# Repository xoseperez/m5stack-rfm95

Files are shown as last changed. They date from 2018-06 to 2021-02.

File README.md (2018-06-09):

# M5Stack TTN Node

This is a LoRaWAN node based on the great M5Stack development platform.
It uses a RFM95 by HopeRF and the standard LMIC stack.
The sample code is configured to connect to The Things Network using EU frequency, but you can easily change that.






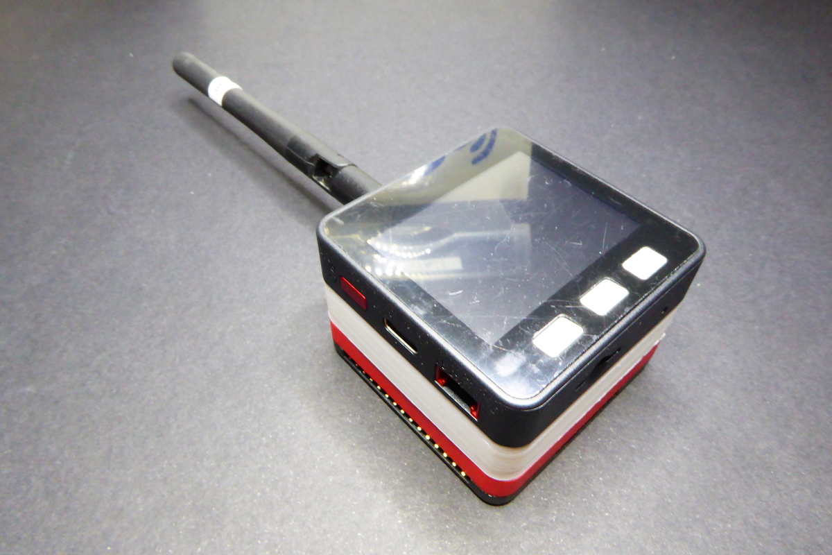
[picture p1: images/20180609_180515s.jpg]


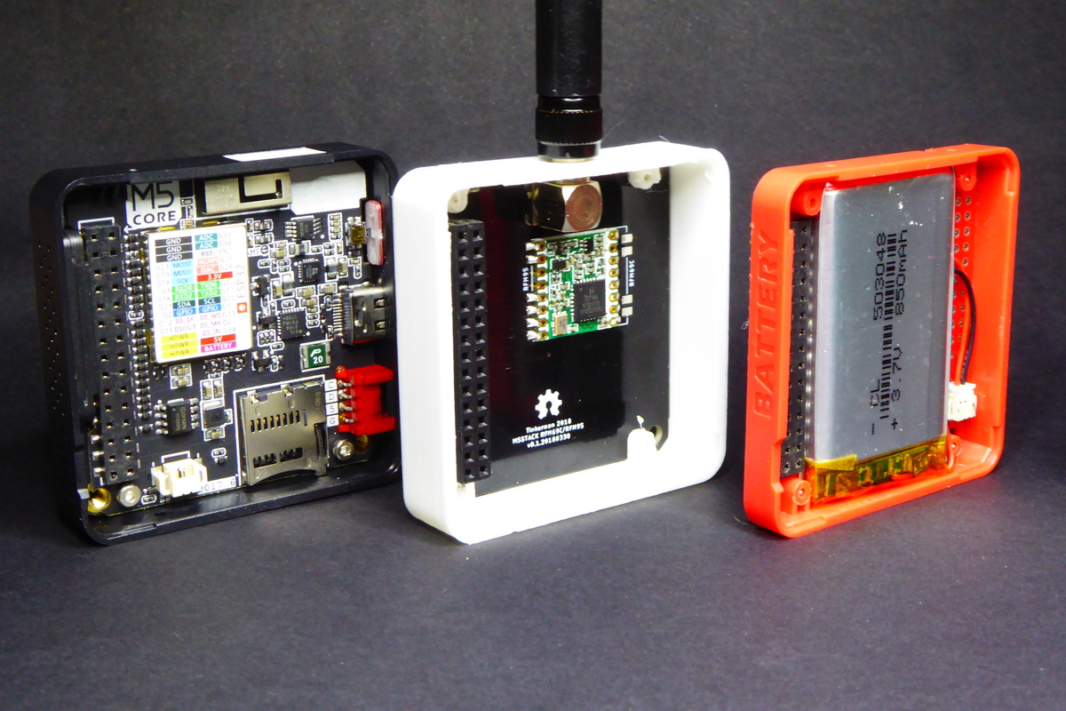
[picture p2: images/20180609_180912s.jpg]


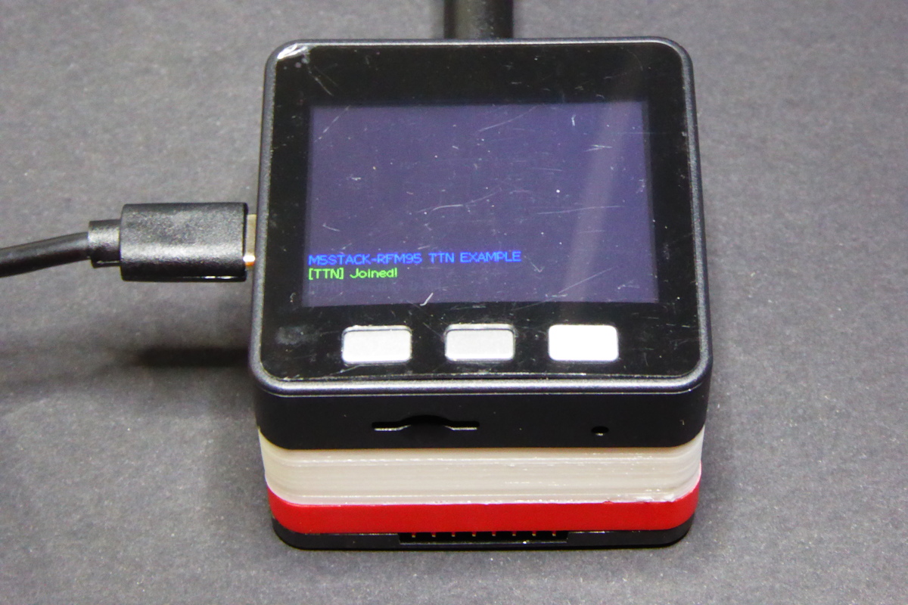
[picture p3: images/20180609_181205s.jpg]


This repository contains:

* PCB schematics, layout (for Eagle) and gerbers.
* 3D model of different enclosure options (bottom layer, middle layer), both OpenSCAD and STL files.
* Sample code that sends an auto-increment number and sleeps the board.

## License

Copyright (C) 2018 by Xose Pérez (@xoseperez)

This program is free software: you can redistribute it and/or modify
it under the terms of the GNU General Public License as published by
the Free Software Foundation, either version 3 of the License, or
(at your option) any later version.

This program is distributed in the hope that it will be useful,
but WITHOUT ANY WARRANTY; without even the implied warranty of
MERCHANTABILITY or FITNESS FOR A PARTICULAR PURPOSE.  See the
GNU General Public License for more details.

You should have received a copy of the GNU General Public License
along with this program.  If not, see <http://www.gnu.org/licenses/>.

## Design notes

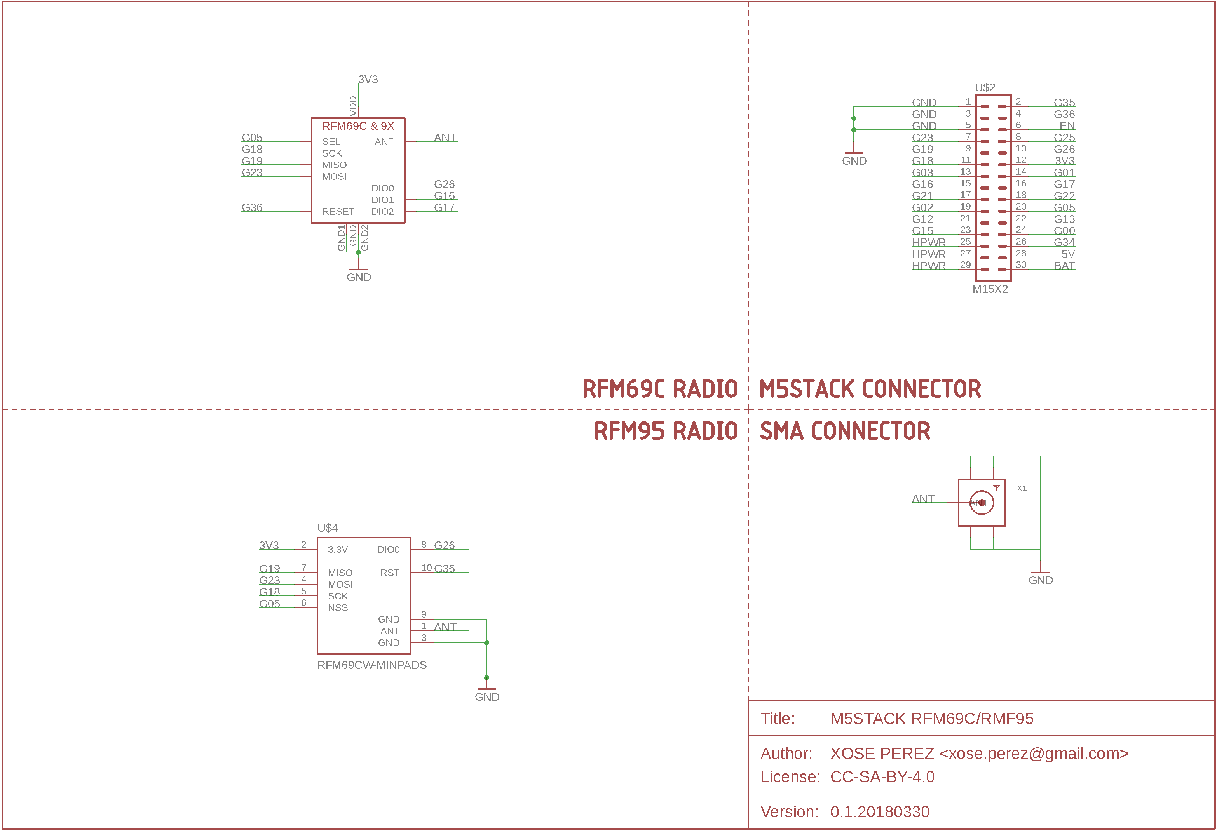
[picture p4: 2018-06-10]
pcb/m5stack-rfm95.v1.0.20180330.schematic.png

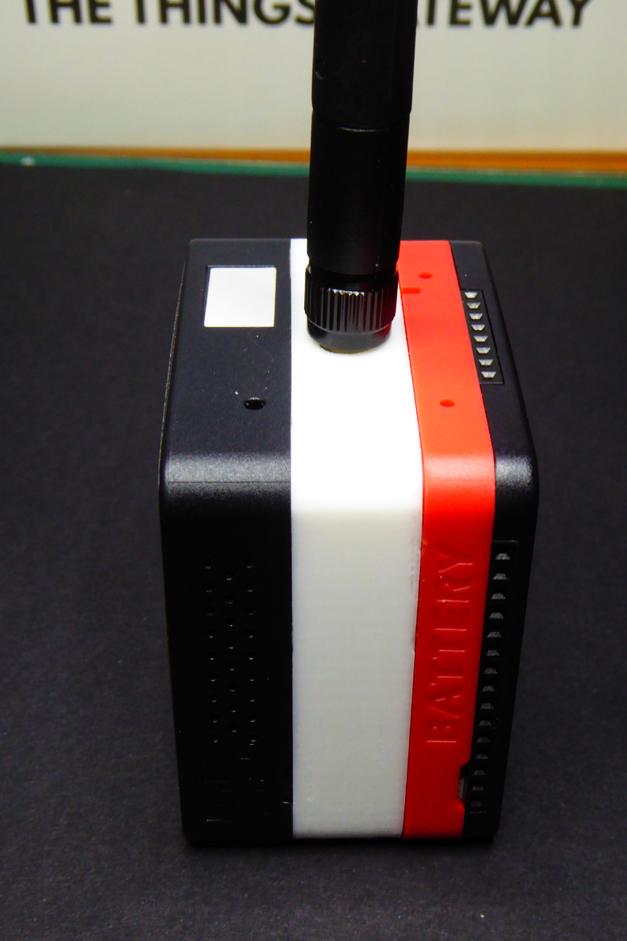
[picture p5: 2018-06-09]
images/20180609_180540s.jpg

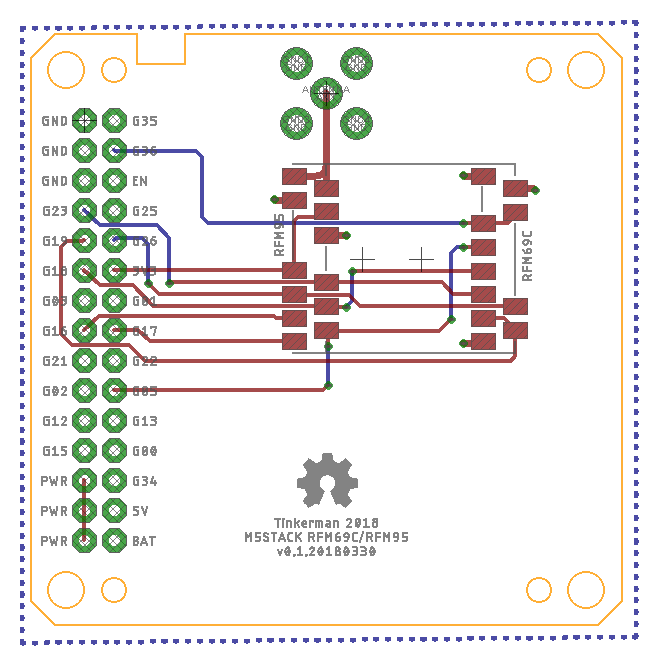
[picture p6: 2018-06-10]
pcb/m5stack-rfm95.v1.0.20180330.layout.png

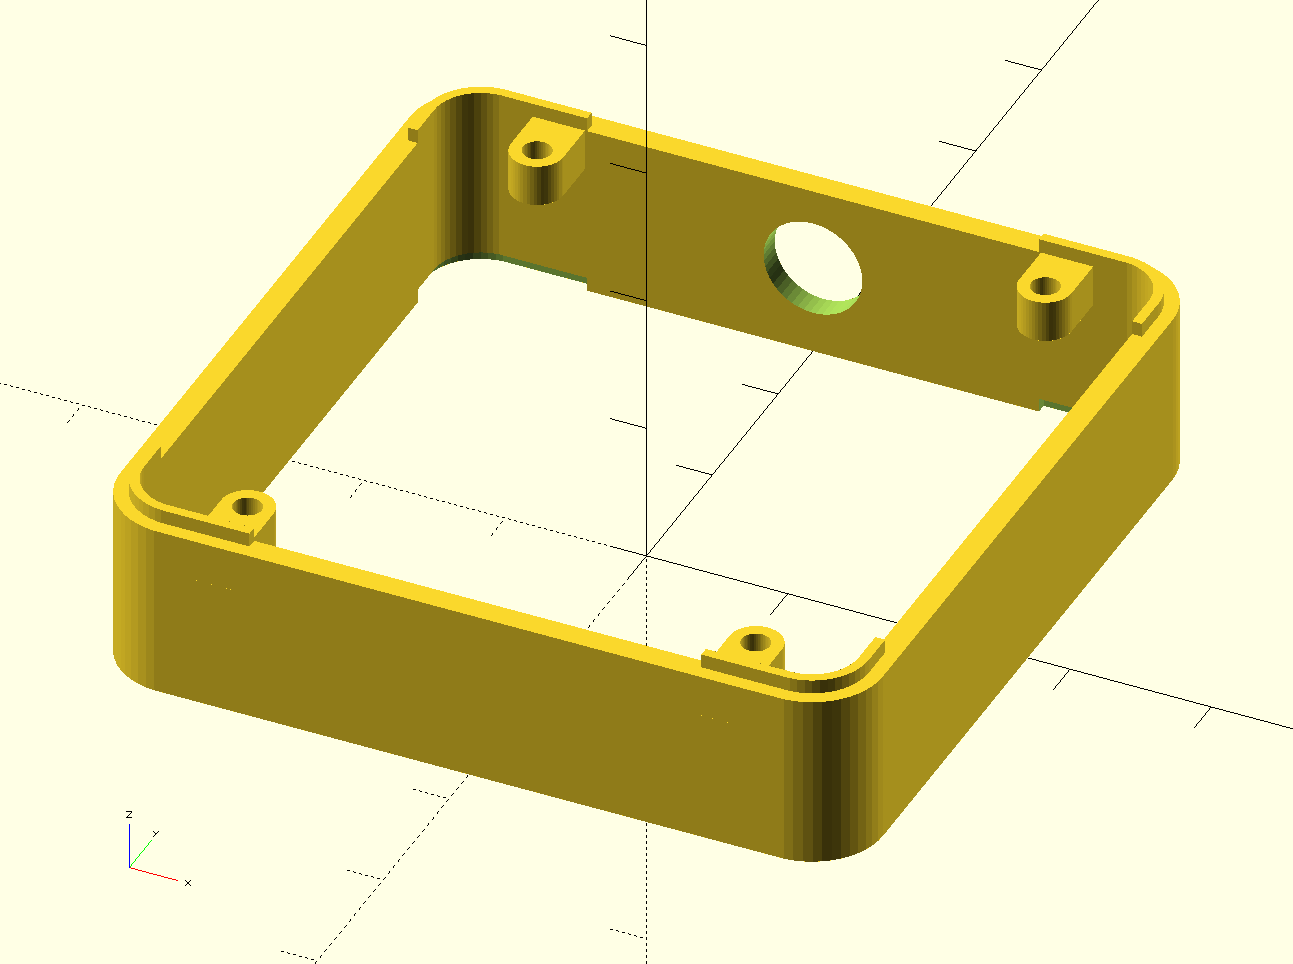
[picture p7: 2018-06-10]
enclosure/m5stack-rfm95.middle.png

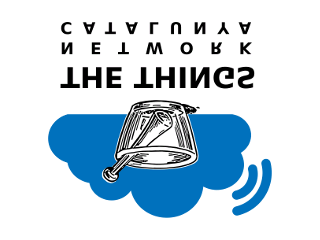
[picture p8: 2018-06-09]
tools/ttncat.bmp

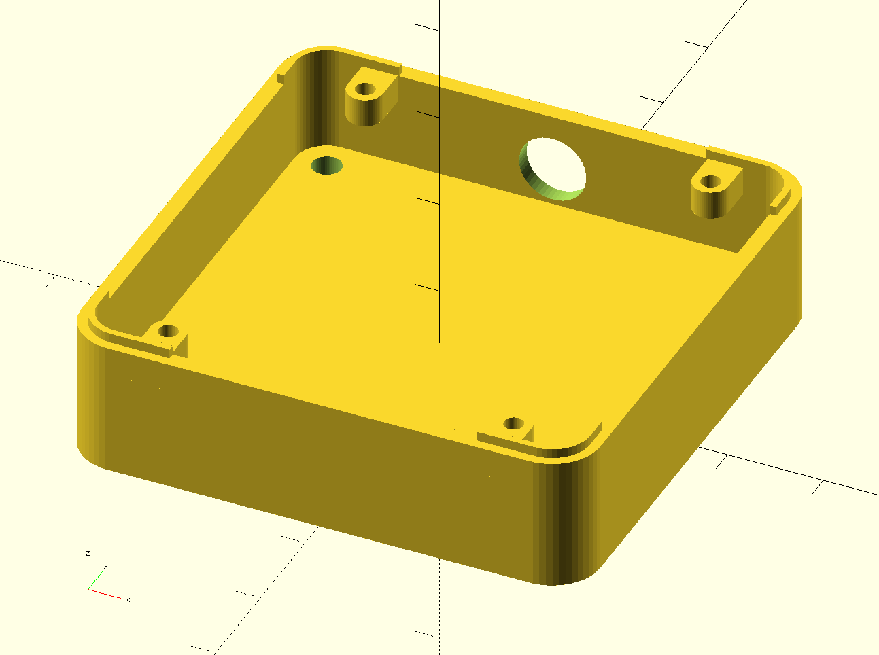
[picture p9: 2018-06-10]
enclosure/m5stack-rfm95.bottom.png

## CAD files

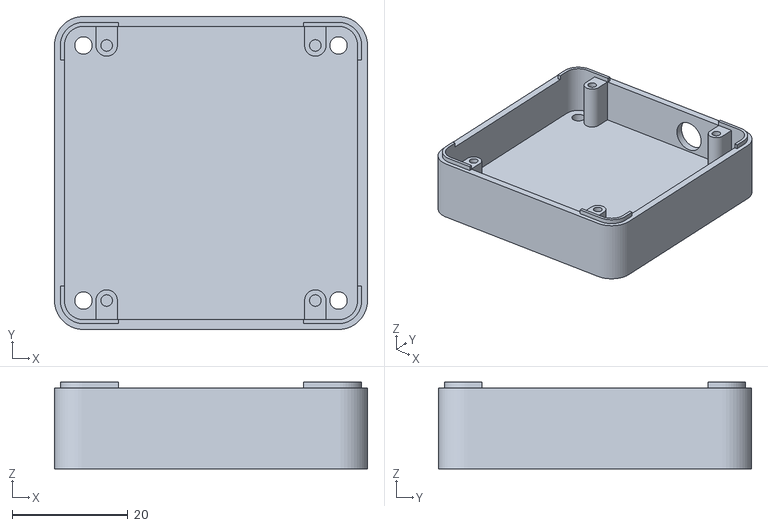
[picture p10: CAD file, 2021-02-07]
enclosure/m5stack-rfm95-bottom-v2.stl
54.0 x 54.0 x 15.0

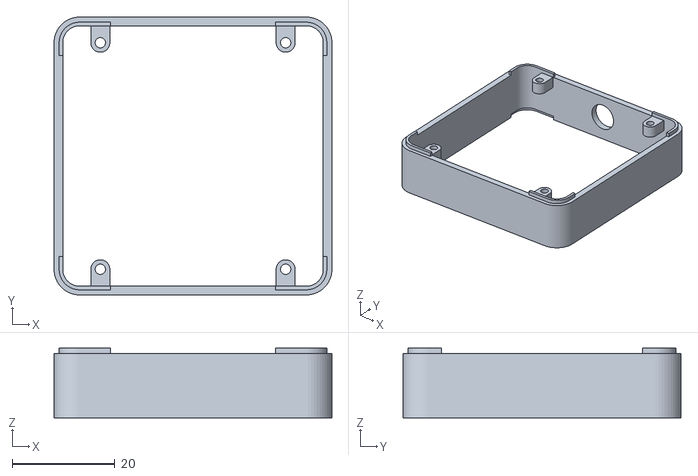
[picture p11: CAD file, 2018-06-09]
enclosure/m5stack-rfm95-middle.stl
54.0 x 54.0 x 13.5

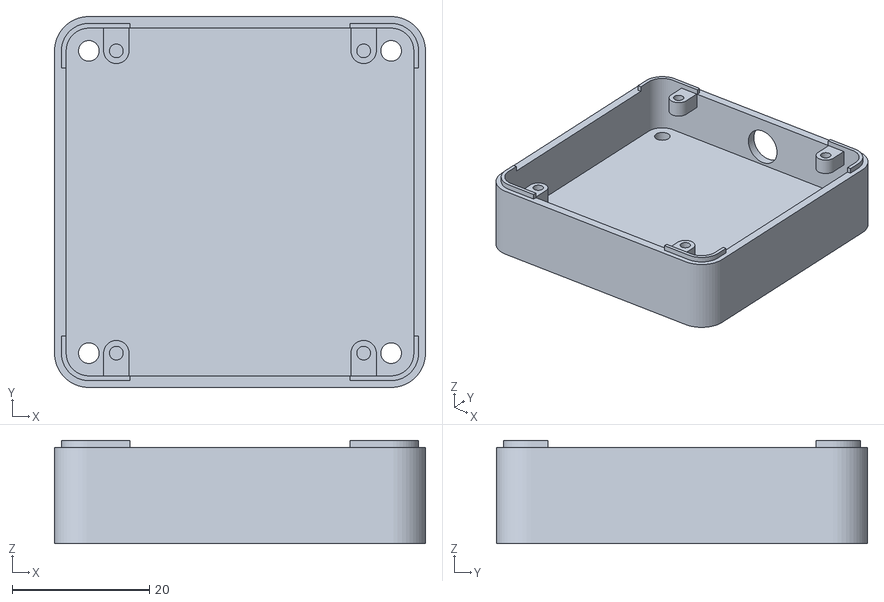
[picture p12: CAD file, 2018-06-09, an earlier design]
enclosure/m5stack-rfm95-bottom.stl
54.0 x 54.0 x 15.0

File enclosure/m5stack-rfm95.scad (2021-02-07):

// -------------------------------------------------
// Settings
// -------------------------------------------------

$fn = 50;

// -------------------------------------------------
// Configuration
// -------------------------------------------------

outer_size = 54.0;
outer_corner = 5.0;
wall_width = 1.7;
wall_height = 10.0;
tab_width = 0.7;
tab_height = 1.0;
hole_height = 10.0;
top_height = 4.0;
antenna_cfg = 2;

// -------------------------------------------------

inner_size = outer_size - 2 * wall_width;
inner_corner_diameter = outer_corner - wall_width;

// -------------------------------------------------
// Modules
// -------------------------------------------------

module wall(outer, width, corner) {

    inner = outer - 2 * width;
    inner_corner = corner - width;

    difference() {

        minkowski() {
            square(outer - 2 * corner, true);
            circle(corner);
        }


        minkowski() {
            square(inner - 2 * inner_corner, true);
            circle(inner_corner);
        }

    }

}

module walls() {
    wall(outer_size, wall_width, outer_corner);
}

module tabs() {
    outer = outer_size + (tab_width - wall_width) * 2;
    corner = outer_corner + (tab_width - wall_width);
    difference() {
        wall(outer, tab_width, corner);
        square([32,outer_size], true);
        square([outer_size,39], true);
    }
}

module hole() {
    translate([18,22]) {
        difference() {
            union() {
                circle(3.7/2);
                translate([-3.7/2,0]) square([3.7,5]);
            }
            circle(2.0/2);
        }
    }
}

module holes() {
    hole();
    mirror([1,0,0]) hole();
    mirror([0,1,0]) {
        hole();
        mirror([1,0,0]) hole();
    }
}

module antenna() {
    rotate([90,0,0]) linear_extrude(wall_width*2) circle(7/2);
}

module screw() {
    linear_extrude(top_height) circle(3/2);
    linear_extrude(top_height/2) circle(6/2);
}

module top() {

    minkowski() {
        square(outer_size - 2 * outer_corner, true);
        circle(outer_corner);
    }

}

module bottom_layer() {
    union() {
        translate([0,0,top_height]) {
            difference() {
                linear_extrude(wall_height) walls();
                if (antenna_cfg == 1) translate([0,outer_size/2,4]) antenna();
                if (antenna_cfg == 2) translate([7.5,outer_size/2,4]) antenna();
                if (antenna_cfg == 3) translate([7.5,outer_size/2,4]) antenna();
                if (antenna_cfg == 3) translate([-7.5,outer_size/2,4]) antenna();
            }
            translate([0,0,wall_height-hole_height]) {
                linear_extrude(hole_height) holes();
            }
            translate([0,0,wall_height]) {
                linear_extrude(tab_height) tabs();
            }
        }
        difference() {
            linear_extrude(top_height) top();
            translate([22,-22]) screw();
            translate([-22,-22]) screw();
            translate([-22,22]) screw();
            translate([22,22]) screw();
        }
    }
}

module middle_layer() {
    height = 12.5;
    difference() {
        union() {
            difference() {
                linear_extrude(height) walls();
                translate([0,outer_size/2,height-6]) antenna();
            }
            translate([0,0,height-hole_height]) {
                linear_extrude(hole_height) holes();
            }
            translate([0,0,height]) {
                linear_extrude(tab_height) tabs();
            }
        }
        linear_extrude(tab_height) tabs();
    }
}

// -------------------------------------------------
// Entry points
// -------------------------------------------------

bottom_layer();
//middle_layer();

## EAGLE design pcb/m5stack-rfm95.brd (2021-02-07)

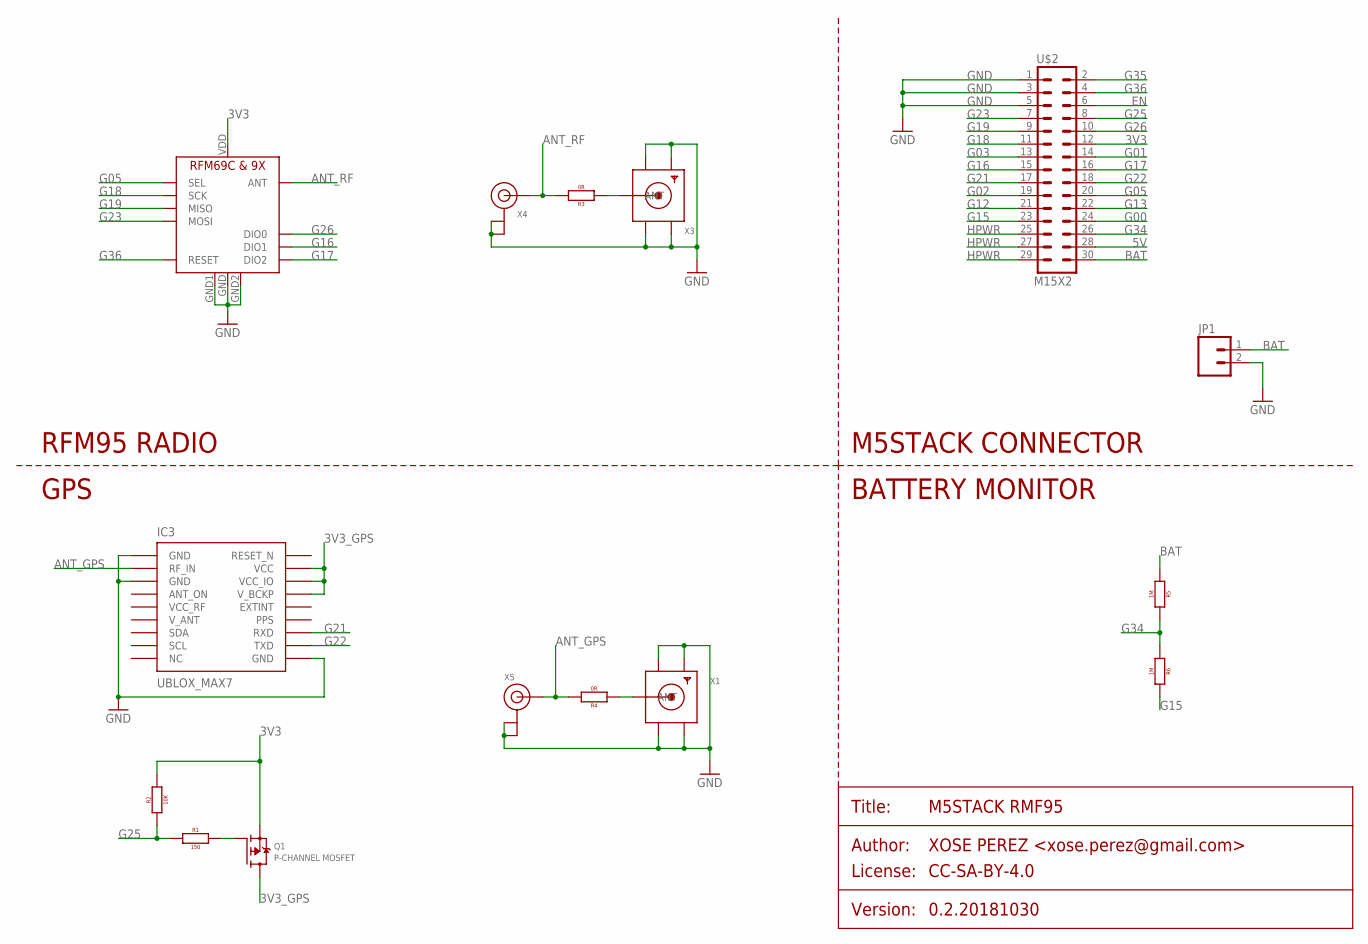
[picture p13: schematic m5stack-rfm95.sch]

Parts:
IC1: RFM69HCW-RFM95; RFM69HCW-RFM95-MINPADS
IC3: UBLOX_MAX7
JP1: M02-JST-2MM-SMT; JST-2-SMD
Q1: P-CHANNEL MOSFET; SOT23-R
R1: 150; 0805
R2: 10K; 0805
R3, R4: 0R; 0805
R5, R6: 1M; 0805
U$2: M15X2; 2X15
X1, X3: SMACONNECTOR; SMA90_DIP
X4, X5: ANTENNA_U.FL; U.FL

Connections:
3V3: IC1.VDD (VCC), Q1.2 (S), R2.2, U$2.12
3V3_GPS: IC3.P$6 (V_BCKP), IC3.P$7 (VCC_IO), IC3.P$8 (VCC), Q1.3 (D)
5V: U$2.28
ANT_GPS: IC3.P$11 (RF_IN), R4.2, X5.3 (SIGNAL)
ANT_RF: IC1.ANT, R3.2, X4.3 (SIGNAL)
BAT: JP1.1 (2), R5.1, U$2.30
EN: U$2.6
G00: U$2.24
G01: U$2.14
G02: U$2.19
G03: U$2.13
G05: IC1.NSS (SEL), U$2.20
G12: U$2.21
G13: U$2.22
G15: R6.2, U$2.23
G16: IC1.DIO1, U$2.15
G17: IC1.DIO2, U$2.16
G18: IC1.SCK, U$2.11
G19: IC1.MISO, U$2.9
G21: IC3.P$3 (RXD), U$2.17
G22: IC3.P$2 (TXD), U$2.18
G23: IC1.MOSI, U$2.7
G25: R1.1, R2.1, U$2.8
G26: IC1.DIO0, U$2.10
G34: R5.2, R6.1, U$2.26
G35: U$2.2
G36: IC1.RESET, U$2.4
GND: IC1.GND, IC1.GND1, IC1.GND2, IC3.P$1 (GND), IC3.P$10 (GND), IC3.P$12 (GND), JP1.2 (1), U$2.1, U$2.3, U$2.5, X1.GND1, X1.GND2, X1.GND3, X1.GND4, X3.GND1, X3.GND2, X3.GND3, X3.GND4, X4.1 (GND), X4.2 (GND), X5.1 (GND), X5.2 (GND)
HPWR: U$2.25, U$2.27, U$2.29
unnamed: R4.1, X1.ANTENNA (ANT)
unnamed: R3.1, X3.ANTENNA (ANT)
unnamed: Q1.1 (G), R1.2
VCC_RF: IC3.P$14 (VCC_RF)
V_ANT: IC3.P$15 (V_ANT)

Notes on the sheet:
RFM95 RADIO
M5STACK CONNECTOR
GPS
BATTERY MONITOR

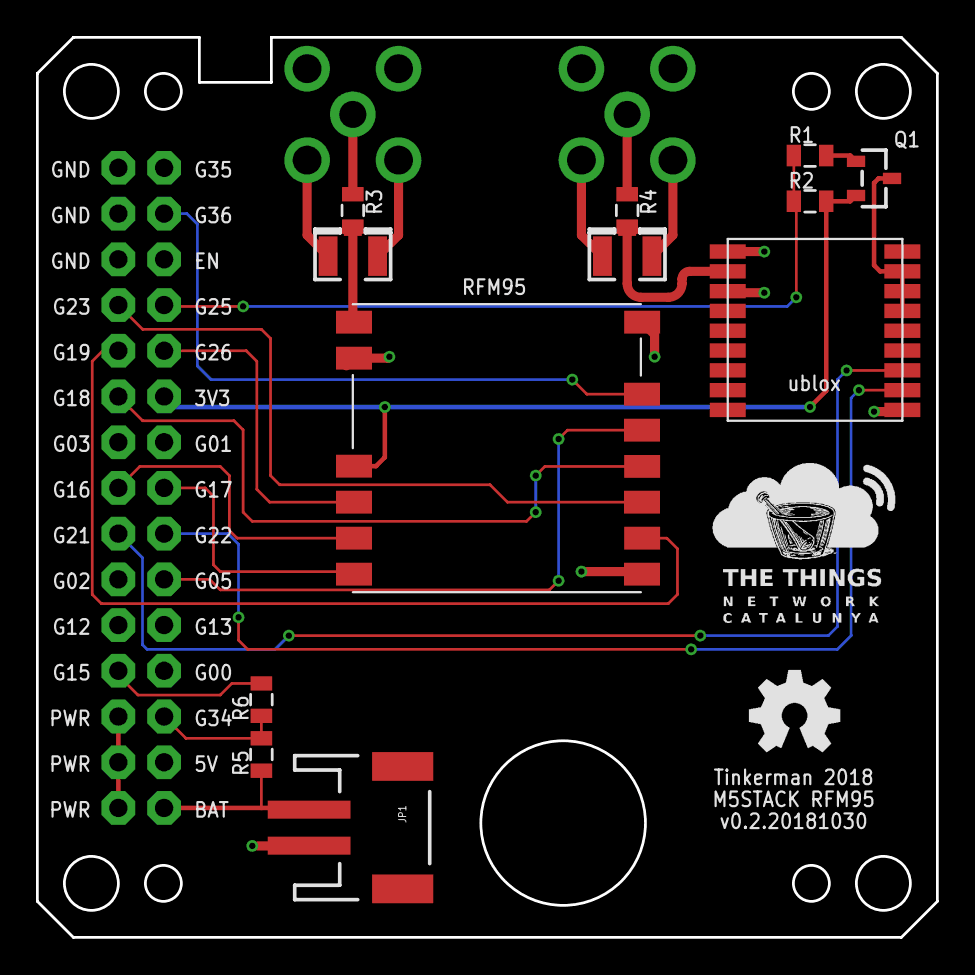
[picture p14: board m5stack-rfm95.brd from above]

Board: 2 copper layers, 50.0 x 50.0 mm, 15 parts (0 on the bottom side), 23 nets.

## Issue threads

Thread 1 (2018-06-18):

Hard questions

janseta, 2018-06-18:
Hi,

Is possible to get someninfonabou the hard needed?

I mean some tech info about the hard to kwon where to get the hard:
the antenna, the conector..

xoseperez, 2018-06-19:
Do you mean the Bill of Materials? Sure, I should have addee it already.

janseta, 2018-06-19:
Yes, I mean the tech specs of the materials needed..
a Billl would be great!

Another sugestion:
if you just made a HOLE on the PCB , you could atach a battery in the conector that the M5Stack has in the core itself..
In that case, you will not need the battery module...

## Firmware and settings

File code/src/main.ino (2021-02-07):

/*

M5stack TTN Node
Main module

Copyright (C) 2018 by Xose Pérez <xose dot perez at gmail dot com>

This sketch requires M5Stack library by M5Stack
https://github.com/m5stack/M5Stack

This sketch requires LMIC library by Matthijs Kooijman
https://github.com/matthijskooijman/arduino-lmic

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
*/

#include "configuration.h"
#include <M5Stack.h>
#include <rom/rtc.h>
#include <CayenneLPP.h>

// Message counter, stored in RTC memory, survives deep sleep
RTC_DATA_ATTR uint32_t count = 0;

// Number of sleeping intervals left, stored in RTC memory, survives deep sleep
RTC_DATA_ATTR uint8_t sleep_intervals = 0;

// Whether to go deep sleep or power off
bool _poweroff = false;

// Cayenne buffer
CayenneLPP lpp(51);

// -----------------------------------------------------------------------------
// Application
// -----------------------------------------------------------------------------

void send() {

    char buffer[64];

    /*
    
    Channel definition for trackers:

    CHANNEL 0: counter (digital_out_0)
    CHANNEL 1: gps (gps_1.altitude gps_1.latitude gps_1.longitude)
    CHANNEL 2: temperature (temperature_2)
    CHANNEL 3: accelerometer (accelerometer_3.x accelerometer_3.y accelerometer_3.z)
    CHANNEL 4: battery (analog_out_4) in volts
    CHANNEL 5: sats (digital_out_5)
    CHANNEL 6: hdop (analog_out_4)

    */

    lpp.reset();
    lpp.addDigitalOutput(0, count);

    snprintf(buffer, sizeof(buffer),"[MSG] Message #%03d\n", (uint8_t) (count & 0xFF));
    screen_print(buffer, LIGHTGREY);

    #if GPS_ENABLE
        if (gps_valid()) {
            
            double lon = gps_longitude();
            double lat = gps_latitude();
            snprintf(buffer, sizeof(buffer),"[GPS] %11.6f %10.6f\n", lon, lat);
            screen_print(buffer, LIGHTGREY);

            lpp.addGPS(1, lat, lon, gps_altitude());
            //lpp.addAnalogOutput(4, battery());
            lpp.addDigitalOutput(5, gps_sats());
            lpp.addAnalogOutput(6, gps_hdop());

        }
    #endif

    #if LORAWAN_CONFIRMED_EVERY > 0
        bool confirmed = (count % LORAWAN_CONFIRMED_EVERY == 0);
    #else
        bool confirmed = false;
    #endif

    ttn_cnt(count);
    ttn_send(lpp.getBuffer(), lpp.getSize(), LORAWAN_PORT, confirmed);

    count++;

}

void callback(uint8_t message) {

    if (EV_JOINING == message) screen_print("[TTN] Joining...\n");
    if (EV_JOINED == message) screen_print("[TTN] Joined!\n");
    if (EV_JOIN_FAILED == message) screen_print("[TTN] Join failed\n", RED);
    if (EV_REJOIN_FAILED == message) screen_print("[TTN] Rejoin failed\n", RED);
    if (EV_RESET == message) screen_print("[TTN] Reset\n", BLUE);
    if (EV_LINK_DEAD == message) screen_print("[TTN] Link dead\n", RED);
    if (EV_ACK == message) screen_print("[TTN] ACK received\n");
    if (EV_PENDING == message) screen_print("[TTN] Message discarded\n", RED);
    if (EV_QUEUED == message) screen_print("[TTN] Message queued\n");

    if (EV_TXCOMPLETE == message) {

        screen_print("[TTN] Message sent\n", LIGHTGREY);

        #if SLEEP_BETWEEN_MESSAGES

            // Show the going to sleep message on the screen
            char buffer[64];
            if (_poweroff) {
                snprintf(buffer, sizeof(buffer), "[M5S] Power off in %u seconds\n", (int) (MESSAGE_TO_SLEEP_DELAY / 1000));
            } else {
                snprintf(buffer, sizeof(buffer), "[M5S] Going to sleep in %u seconds\n", (int) (MESSAGE_TO_SLEEP_DELAY / 1000));
            }
            screen_print(buffer);
            delay(MESSAGE_TO_SLEEP_DELAY);
            screen_off();

            // GPS
            #if GPS_ENABLE
                if (gps_connected()) gps_disconnect();
            #endif

            // Set the left most button to wake the board
            sleep_interrupt(BUTTON_A_PIN, LOW);

            // If power off sleep forever
            if (_poweroff) sleep_forever();

            // We sleep in blocks of 30' because of this:
            // http://forum.m5stack.com/topic/62/ip5306-automatic-standby
            // so we calculate the number of blocks to sleep

            // We sleep for the interval between messages minus the current millis
            // this way we distribute the messages evenly every TX_INTERVAL millis
            uint32_t sleep_for = TX_INTERVAL - millis();

            // How many sleep blocks do we have to sleep?
            sleep_intervals = sleep_for / MAX_SLEEP_INTERVAL;

            // Trigger the deep sleep mode
            // The first block might be shorter than MAX_SLEEP_INTERVAL
            sleep_millis(sleep_for % MAX_SLEEP_INTERVAL);

        #endif

    }

    if (EV_RESPONSE == message) {

        screen_print("[TTN] Response: ");

        size_t len = ttn_response_len();
        uint8_t data[len];
        ttn_response(data, len);

        char buffer[6];
        for (uint8_t i=0; i<len; i++) {
            snprintf(buffer, sizeof(buffer), "0x%02X ", data[i]);
            screen_print(buffer);
        }

        screen_print("\n");

    }

}

void setup() {

    // Awake from deep sleep (reason 5)?
    if (5 == rtc_get_reset_reason(0)) {

        // Is the button pressed (HIGH means "no")?
        if (digitalRead(BUTTON_A_PIN) == HIGH) {

            // If we are not done yet...
            if (sleep_intervals > 0) {

                // Update the number of intervals left
                --sleep_intervals;

                // Delay a bit so the IP5306 notices it
                delay(SLEEP_DELAY);

                // And go back to sleep
                sleep_interrupt(BUTTON_A_PIN, LOW);
                sleep_millis(MAX_SLEEP_INTERVAL - millis());

            }
        }
    }

    // Debug
    #ifdef DEBUG_PORT
        DEBUG_PORT.begin(SERIAL_BAUD);
    #endif

    // Buttons
    pinMode(BUTTON_A_PIN, INPUT_PULLUP);
    pinMode(BUTTON_B_PIN, INPUT_PULLUP);
    pinMode(BUTTON_C_PIN, INPUT_PULLUP);

    // Setup the screen
    screen_setup();

    // Hello
    screen_print("M5STACK-RFM95 TTN EXAMPLE\n", BLUE);

    // GPS setup
    #if GPS_ENABLE
        gps_connect();
        if (gps_connected()) {
            screen_print("[GPS] GPS connected!\n", GREEN);
            gps_prime(GPS_PRIMING_TIME);
            if (gps_valid()) {
                screen_print("[GPS] GPS position lock!\n", GREEN);
            }
        }
    #endif

    // TTN setup
    if (!ttn_setup()) {
        screen_print("[M5S] Could not find the radio module!\n", RED);
        delay(MESSAGE_TO_SLEEP_DELAY);
        sleep_forever();
    }
    ttn_register(callback);
    ttn_join();
    ttn_sf(LORAWAN_SF);
    ttn_pow(LORAWAN_POW);
    ttn_adr(LORAWAN_ADR);

}

void loop() {

    // Send every TX_INTERVAL millis
    static uint32_t last = 0;
    if (0 == last || millis() - last > TX_INTERVAL) {
        last = millis();
        send();
    }

    // Send on button press
    M5.update();
    if (M5.BtnA.wasPressed()) {
        send();
    }
    if (M5.BtnC.wasPressed()) {
        _poweroff = true;
    }

    ttn_loop();
    
    #if GPS_ENABLE
        gps_loop();
    #endif

}

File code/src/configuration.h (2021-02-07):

/*

M5stack based TTN Tracker

Copyright (C) 2018 by Xose Pérez <xose dot perez at gmail dot com>

This code requires LMIC library by Matthijs Kooijman
https://github.com/matthijskooijman/arduino-lmic

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
*/

#pragma once

#include <Arduino.h>
#include <lmic.h>

void ttn_register(void (*callback)(uint8_t message));

// -----------------------------------------------------------------------------
// Version

// -----------------------------------------------------------------------------

#define APP_NAME                "M5STACK TTN TRACKER"
#define APP_VERSION             "0.3.0"

// -----------------------------------------------------------------------------
// Configuration
// -----------------------------------------------------------------------------

//#define DEBUG_PORT              Serial      // Serial debug port
#define SERIAL_BAUD             115200      // Serial debug baud rate
#define TX_INTERVAL             15000       // Send message every these many millis
#define SLEEP_BETWEEN_MESSAGES  1           // Do sleep between messages
#define MAX_SLEEP_INTERVAL      30000       // Sleep for these many millis
#define SLEEP_DELAY             500         // Time between sleep blocks to keep IP5306 on
#define MESSAGE_TO_SLEEP_DELAY  500         // Time after message before going to sleep
#define LORAWAN_PORT            1           // Port the messages will be sent to
#define LORAWAN_CONFIRMED_EVERY 0           // Send confirmed message every these many messages (0 means never)
#define LORAWAN_SF              DR_SF7      // Spreading factor
#define LORAWAN_POW             14          // Transmitting power in dBm (0 to 14 for EU bands)
#define LORAWAN_ADR             0           // Enable ADR

// -----------------------------------------------------------------------------
// GPS
// -----------------------------------------------------------------------------

#define GPS_ENABLE              0

#define GPS_VIA_BLUETOOTH
#define GPS_ADDRESS             {0x00, 0x80, 0x5A, 0x68, 0x1A, 0x6B}
#define GPS_PIN                 "0000"
#define GPS_PRIMING_TIME        1000

//#define GPS_VIA_SERIAL
#define GPS_RX_PIN              0
#define GPS_TX_PIN              0
#define GPS_BAUDRATE            9600

// -----------------------------------------------------------------------------
// DEBUG
// -----------------------------------------------------------------------------

#ifdef DEBUG_PORT
#define DEBUG_MSG(...) DEBUG_PORT.printf( __VA_ARGS__ )
#else
#define DEBUG_MSG(...)
#endif

// -----------------------------------------------------------------------------
// Custom messages
// -----------------------------------------------------------------------------

#define EV_QUEUED       100
#define EV_PENDING      101
#define EV_ACK          102
#define EV_RESPONSE     103

// -----------------------------------------------------------------------------
// LoRa SPI
// -----------------------------------------------------------------------------

#define SCK_GPIO        18
#define MISO_GPIO       19
#define MOSI_GPIO       23
#define NSS_GPIO        05
#define RESET_GPIO      36
#define DIO0_GPIO       26
#define DIO1_GPIO       16
#define DIO2_GPIO       17

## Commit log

2018-06-09 Fix sleep on battery, added logo
    [general.h, main.ino, screen.ino]
2018-06-10 PCB and 3D printed models images
    [m5stack-rfm95.scad]
2018-09-30 Small rework
    [configuration.h]
2018-11-14 Clean code and send ping every 15s
    [configuration.h]
2021-02-07 MOdified enclosure
    [m5stack-rfm95-bottom-v2.stl, m5stack-rfm95.scad]
2021-02-07 Changes in the PCB
    [m5stack-rfm95.brd, m5stack-rfm95.sch]
2021-02-07 Added BT GPS
    [configuration.h]
2021-02-07 Option to disable GPS code, disabled by default for backwards compatibility
    [configuration.h]

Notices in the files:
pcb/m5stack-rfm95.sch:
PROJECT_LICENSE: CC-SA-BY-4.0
